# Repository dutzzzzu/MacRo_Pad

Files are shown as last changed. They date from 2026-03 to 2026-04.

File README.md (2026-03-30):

## MacRo Pad

A compact macropad with 6 keys, 2 rotary encoders, and a small OLED display.  
It’s designed for quick media control, productivity shortcuts, and future smart home integration.  
Currently built for macOS. Home Assistant integration and Windows support will be added once the hardware is available.

---
## Overview

<table>
  <tr>
    <td align="center">
      <b>Render</b><br>
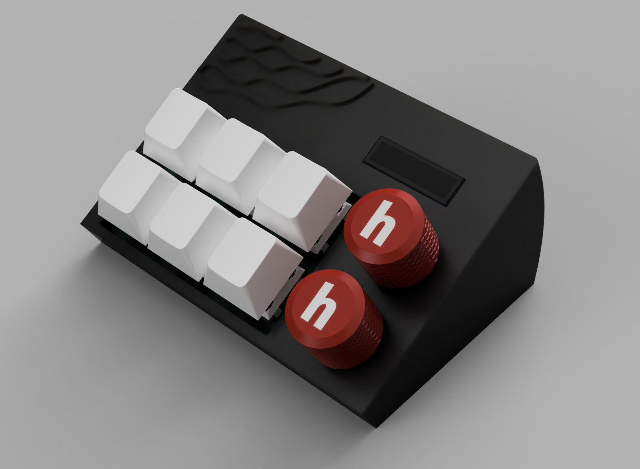
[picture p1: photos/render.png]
      
    </td>
    <td align="center">
      <b>Case</b><br>
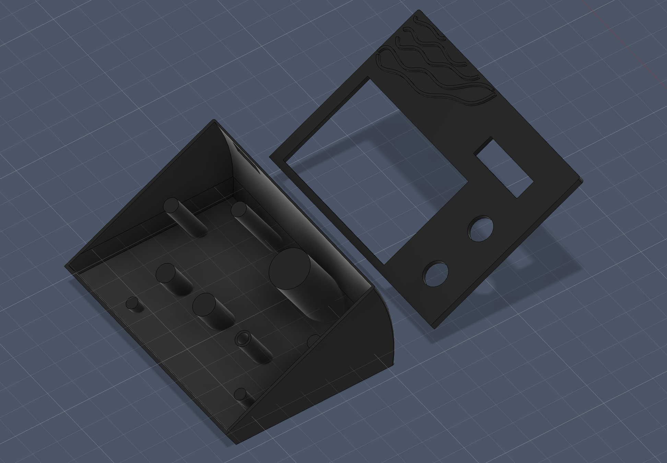
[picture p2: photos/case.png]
      
    </td>
  </tr>
  <tr>
    <td align="center">
      <b>Schematic</b><br>
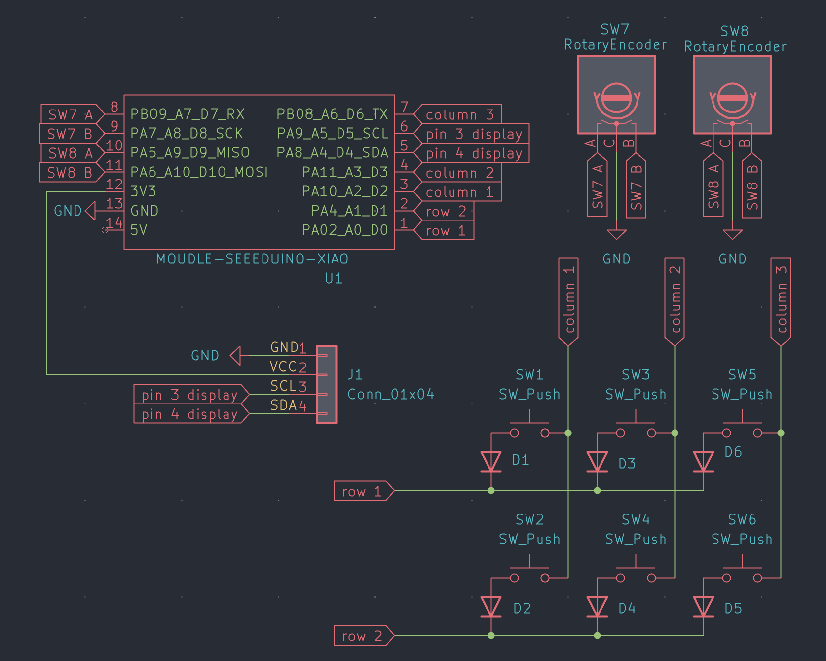
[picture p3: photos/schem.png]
      
    </td>
    <td align="center">
      <b>PCB</b><br>
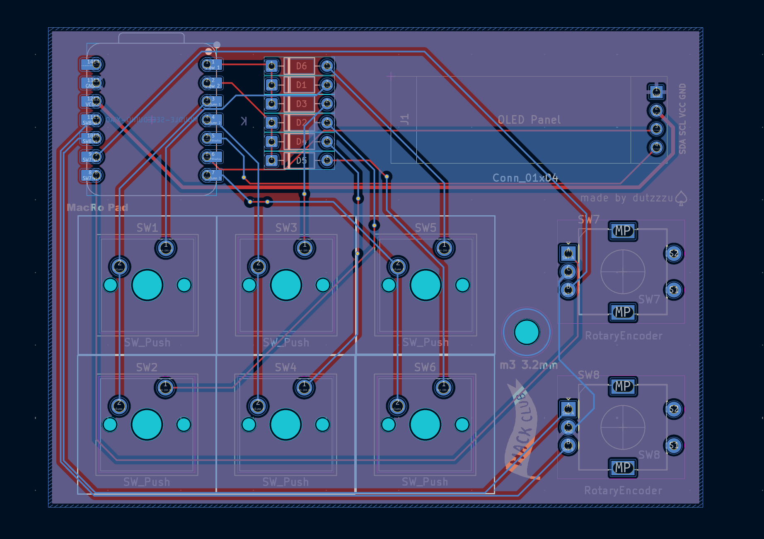
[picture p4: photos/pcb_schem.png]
      
    </td>
  </tr>
</table>

---

## Bill of Materials

| Part | Quantity | Notes |
|---|---|---|
| Seeed XIAO RP2040 | 1 | Main microcontroller |
| MX-style switches | 6 | Mechanical switches |
| DSA keycaps | 6 | Keycaps |
| EC11 rotary encoders | 2 | Rotation only |
| 0.91" OLED display (SSD1306) | 1 | I2C |
| 1N4148 diodes | 6 | Key matrix |
| Custom PCB | 1 | Designed in KiCad |
| 3D printed case | 1 | Custom enclosure |
| 3D printed knobs | 2 | Custom knobs |
| M3 screws | 1 | Assembly |
| M3 heatset inserts | 1 | Mounting |

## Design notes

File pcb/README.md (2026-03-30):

PCB design files for the macropad.
The assembly is made in fusion
## PCB Design

| Layout | PCB (no buttons) |
|---|---|
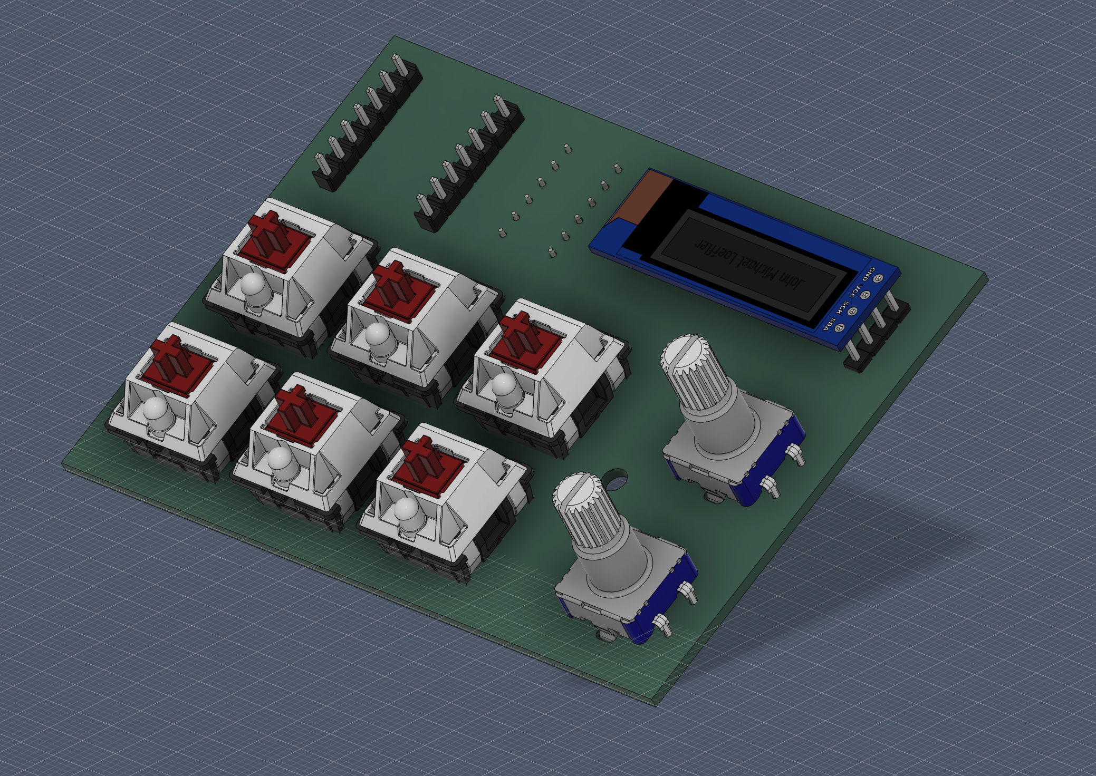
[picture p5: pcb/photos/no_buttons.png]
|  |  |

| Schematic | All Components |
|---|---|
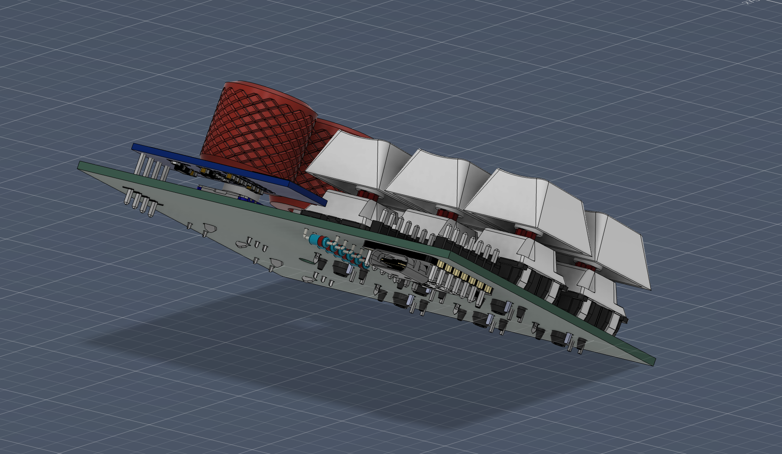
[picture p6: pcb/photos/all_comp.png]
| |  |

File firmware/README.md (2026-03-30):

## Firmware

<table>
<tr>
<td valign="top" width="50%">

### OLED / Encoders
- Encoder 1: volume  
- Encoder 2: brightness / focus volume  
- Key 3: encoder 2 mode  
- Key 6: switch layout  
- OLED shows layout / time / slider  

</td>
<td valign="top" width="50%">

### Productivity

| Key 1 | Key 2 | Key 3 |
|---|---|---|
| Copy | Paste | Encoder mode |

| Key 4 | Key 5 | Key 6 |
|---|---|---|
| Lock screen | Quit app | Switch layout |

</td>
</tr>

<tr>
<td valign="top" width="50%">

### Media

| Key 1 | Key 2 | Key 3 |
|---|---|---|
| Previous track | Next track | Encoder mode |

| Key 4 | Key 5 | Key 6 |
|---|---|---|
| Play / Pause | Open app | Switch layout |

</td>
<td valign="top" width="50%">

### Home Assistant

| Key 1 | Key 2 | Key 3 |
|---|---|---|
| action | action | Encoder mode |

| Key 4 | Key 5 | Key 6 |
|---|---|---|
| action | action | Switch layout |

</td>
</tr>
</table>

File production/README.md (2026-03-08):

# Production

Manufacturing files for the macropad.

| Gerber | Knob |
|---|---|
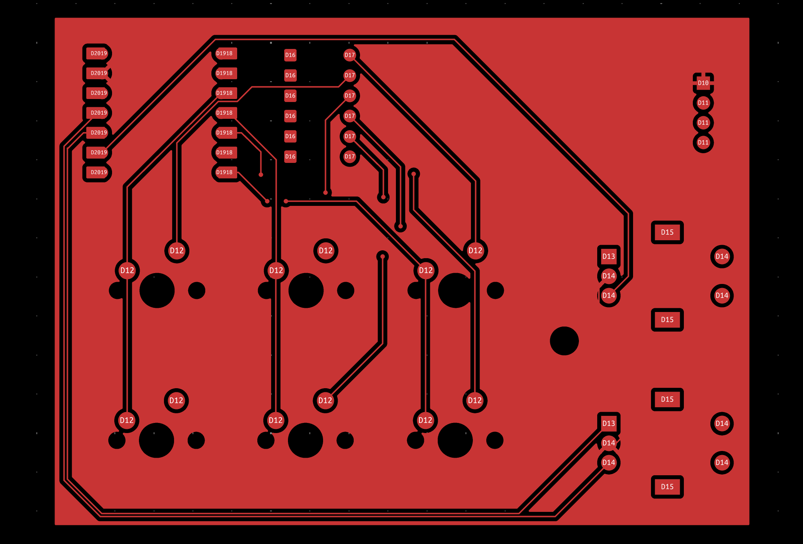
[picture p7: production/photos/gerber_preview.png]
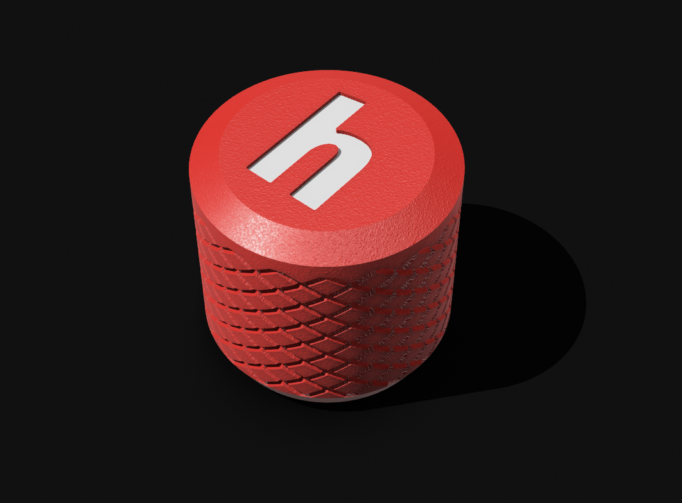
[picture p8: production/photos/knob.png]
|  |  |

| Faceplate | Housing |
|---|---|
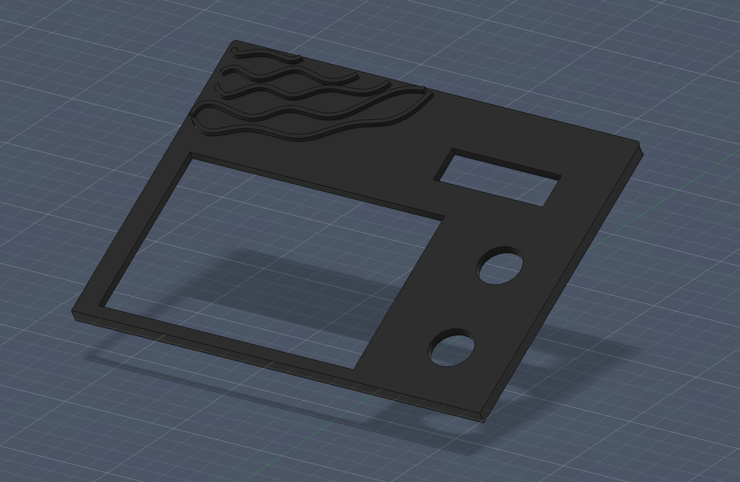
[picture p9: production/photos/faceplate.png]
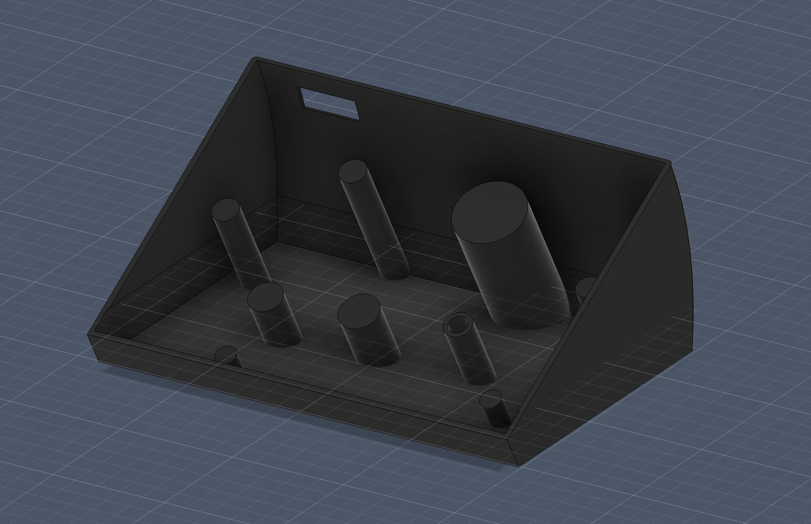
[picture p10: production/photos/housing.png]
|  |  |

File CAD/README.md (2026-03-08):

# CAD

3D models for the MacRo_Pad case.

| Assembly | Case |
|---|---|
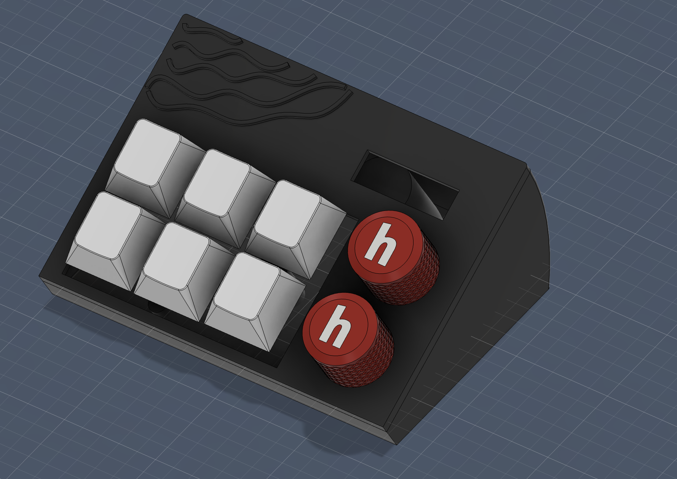
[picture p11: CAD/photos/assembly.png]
|  |  |

| Faceplate | Housing |
|---|---|
|  |  |

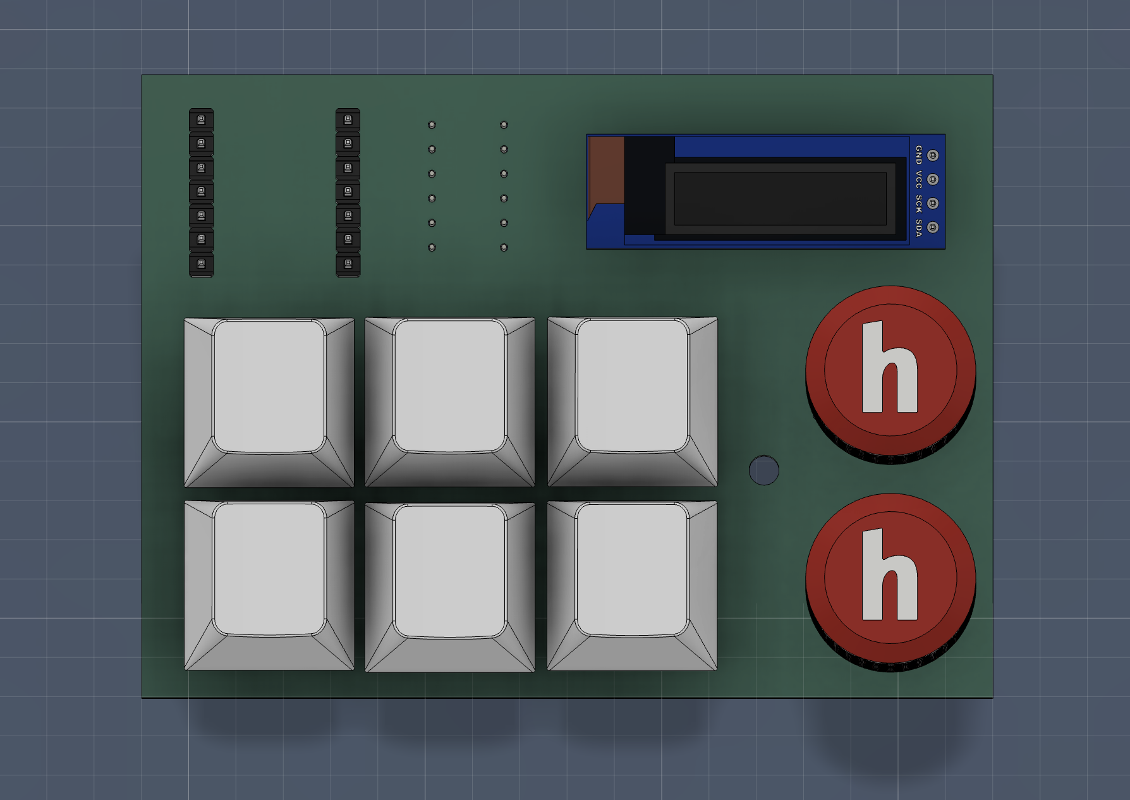
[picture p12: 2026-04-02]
pcb/photos/face.png

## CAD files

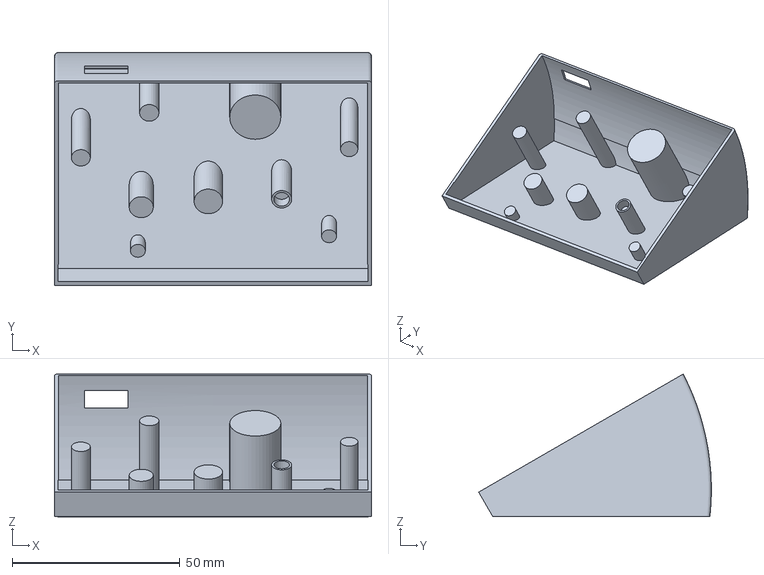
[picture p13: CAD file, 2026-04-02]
CAD/3mf files/housing (1).3mf
94.5 x 69.4 x 42.6 mm

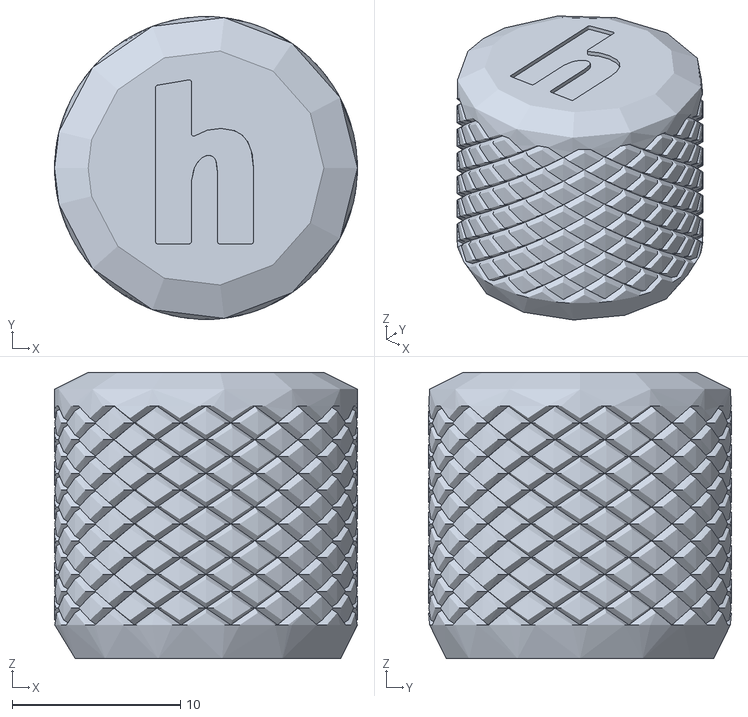
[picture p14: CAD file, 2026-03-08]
production/knurled_knob.step.stl
18.0 x 18.0 x 17.0

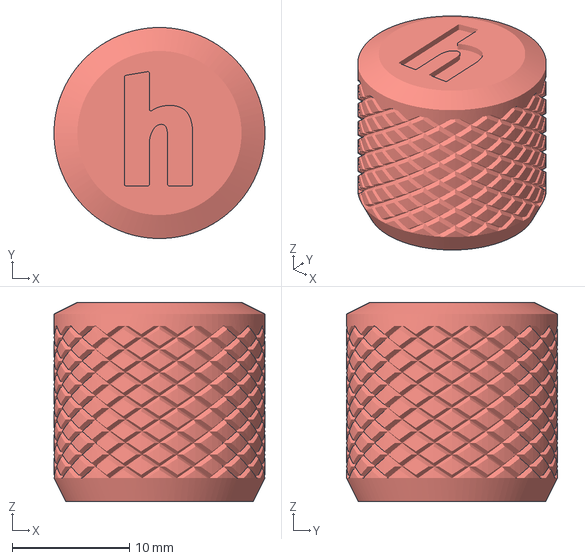
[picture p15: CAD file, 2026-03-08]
CAD/3mf files/knob.3mf
18.0 x 18.0 x 17.0 mm

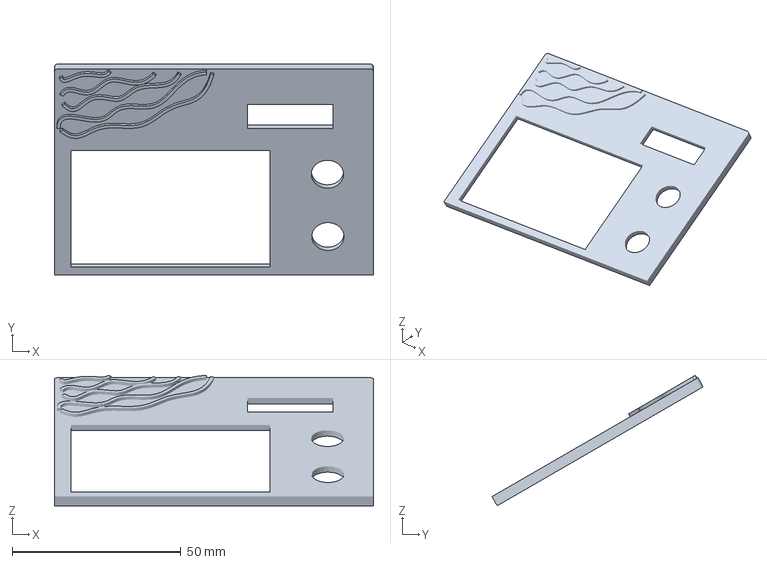
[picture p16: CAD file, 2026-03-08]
CAD/3mf files/faceplate.3mf
94.5 x 62.5 x 38.7 mm

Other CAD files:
CAD/step files/housing .step
production/step files/housing .step
production/step files/knurled_knob.step
production/step files/faceplate.step
CAD/STL files/housing.stl
CAD/step files/housing.step
production/faceplate.stl

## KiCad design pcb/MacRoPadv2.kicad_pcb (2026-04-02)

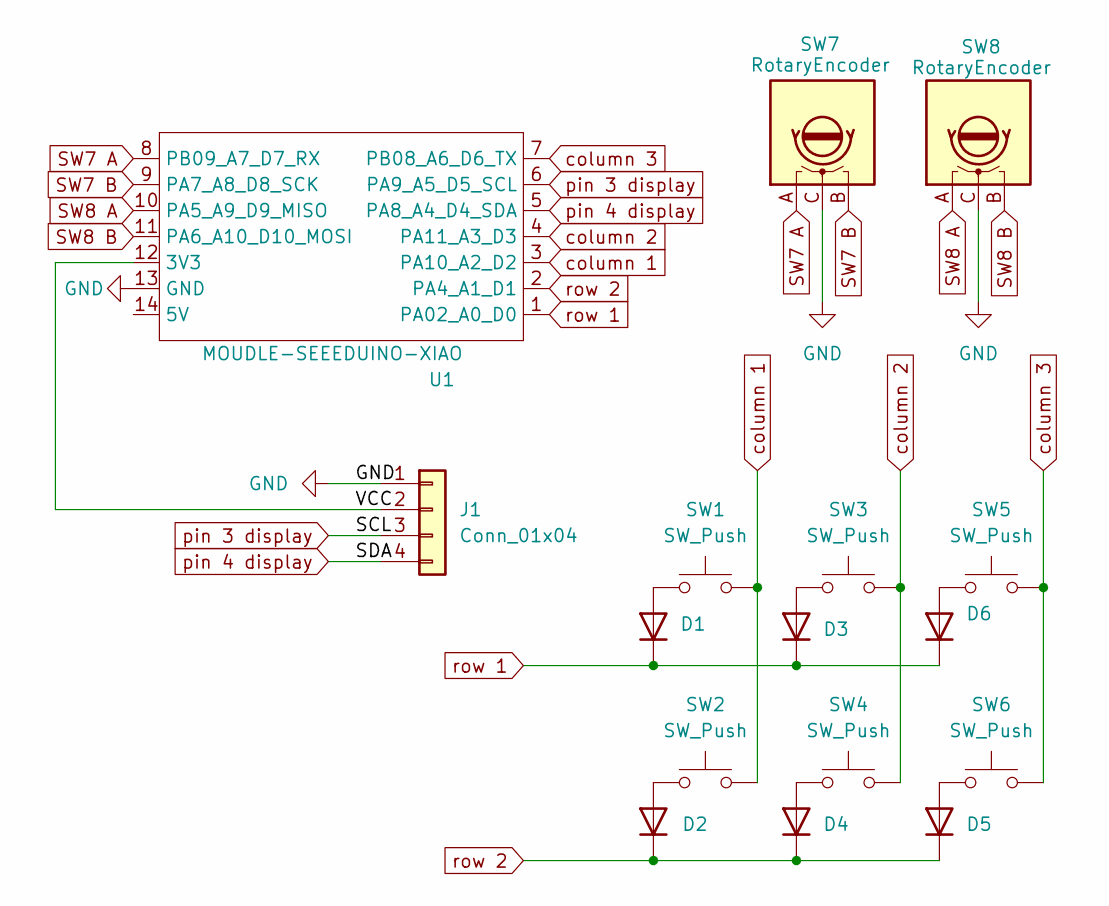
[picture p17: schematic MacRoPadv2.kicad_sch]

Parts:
D1, D2, D3, D4, D5, D6: 1N4148; D_DO-35_SOD27_P7.62mm_Horizontal
J1: Conn_01x04; SSD1306-0.91-OLED-4pin-128x32
SW1, SW2, SW3, SW4, SW5, SW6: SW_Push; SW_Cherry_MX_1.00u_PCB
SW7, SW8: RotaryEncoder; RotaryEncoder_Alps_EC11E-Switch_Vertical_H20mm
U1: MOUDLE-SEEEDUINO-XIAO; XIAO-RP2040-DIP

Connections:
/VCC: J1.2, U1.12 (3V3)
GND: J1.1, SW7.C, SW8.C, U1.13 (GND)
unnamed: D1.2 (A), SW1.1
unnamed: D2.2 (A), SW2.1
unnamed: D3.2 (A), SW3.1
unnamed: D4.2 (A), SW4.1
unnamed: D5.2 (A), SW6.1
unnamed: D6.2 (A), SW5.1
SW7 A: SW7.A, U1.8 (PB09_A7_D7_RX)
SW7 B: SW7.B, U1.9 (PA7_A8_D8_SCK)
SW8 A: SW8.A, U1.10 (PA5_A9_D9_MISO)
SW8 B: SW8.B, U1.11 (PA6_A10_D10_MOSI)
column 1: SW1.2, SW2.2, U1.3 (PA10_A2_D2)
column 2: SW3.2, SW4.2, U1.4 (PA11_A3_D3)
column 3: SW5.2, SW6.2, U1.7 (PB08_A6_D6_TX)
pin 3 display: J1.3, U1.6 (PA9_A5_D5_SCL)
pin 4 display: J1.4, U1.5 (PA8_A4_D4_SDA)
row 1: D1.1 (K), D3.1 (K), D6.1 (K), U1.1 (PA02_A0_D0)
row 2: D2.1 (K), D4.1 (K), D5.1 (K), U1.2 (PA4_A1_D1)

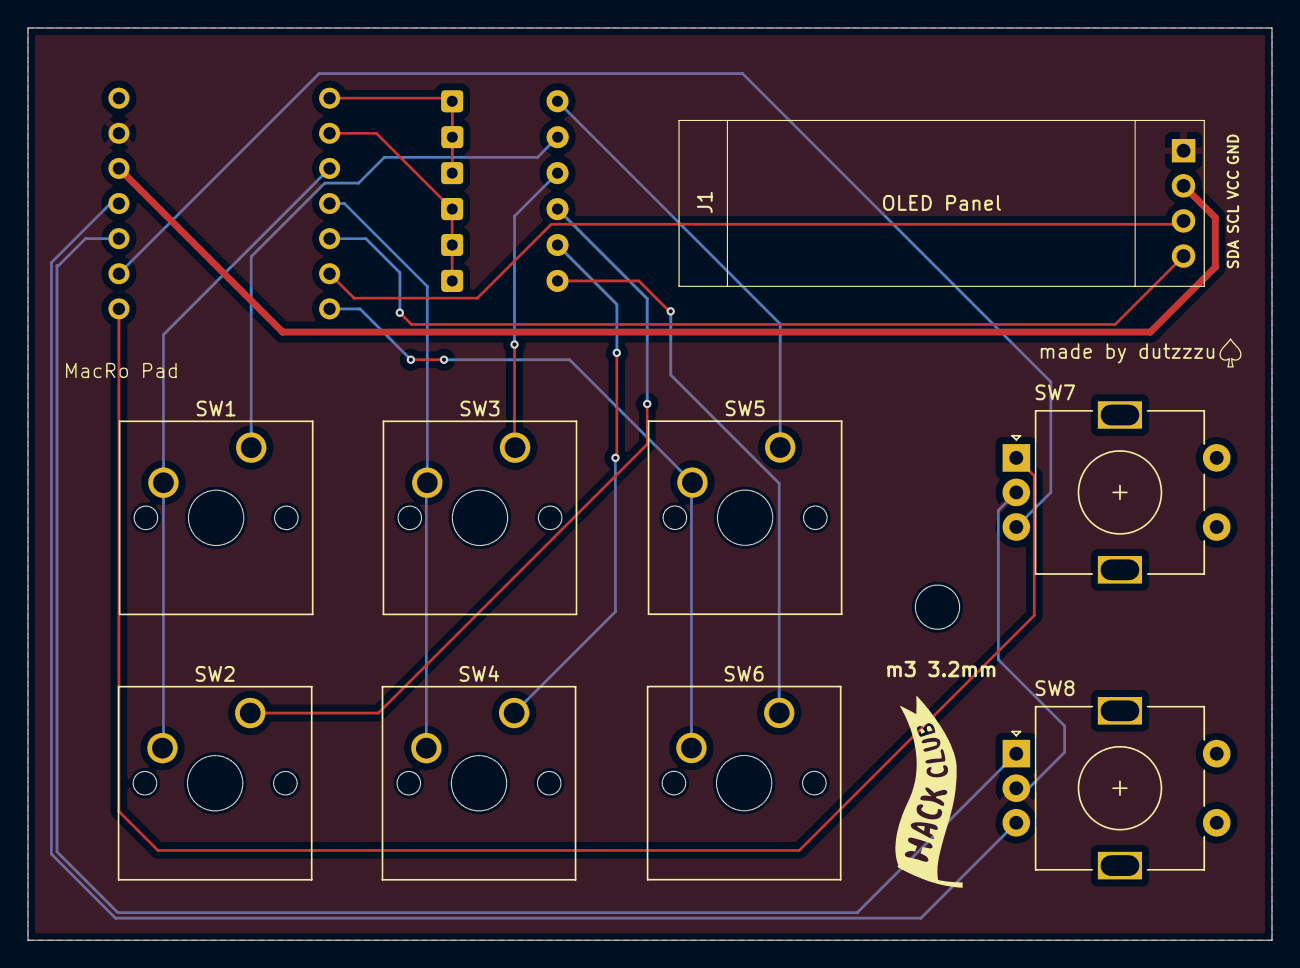
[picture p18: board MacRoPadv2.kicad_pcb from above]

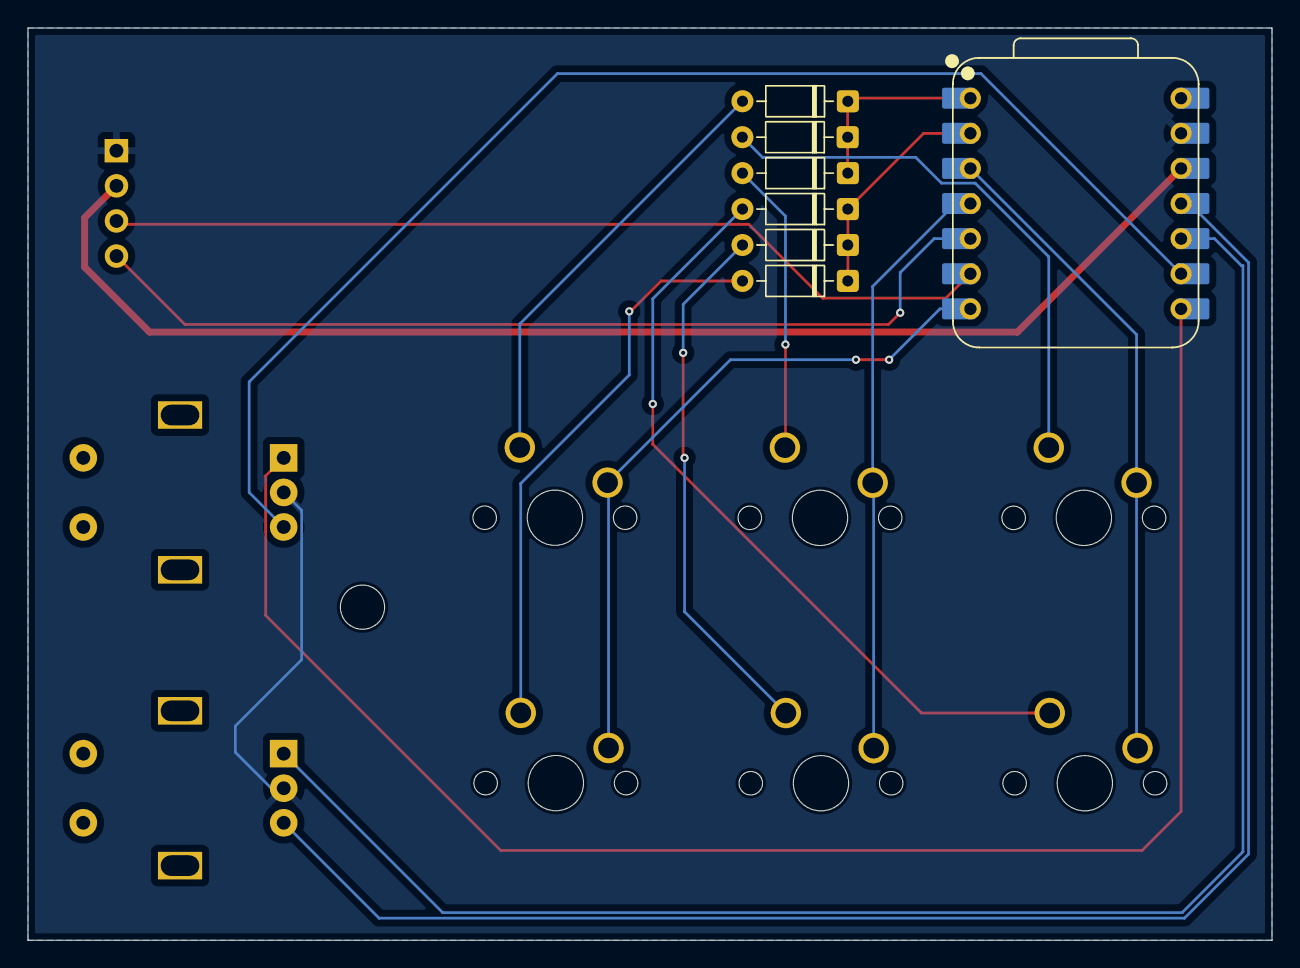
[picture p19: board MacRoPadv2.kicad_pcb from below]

Board: 2 copper layers, 90.0 x 66.0 mm, 16 parts (7 on the bottom side), 19 nets.

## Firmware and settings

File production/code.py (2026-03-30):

import time

try:
    import board
    import busio
    import displayio
    import keypad
    import rotaryio
    import terminalio
    import usb_hid
    from adafruit_display_text import label
    from adafruit_displayio_ssd1306 import SSD1306
    from adafruit_hid.consumer_control import ConsumerControl
    from adafruit_hid.consumer_control_code import ConsumerControlCode
    from adafruit_hid.keyboard import Keyboard
    from adafruit_hid.keycode import Keycode
    from adafruit_hid.keyboard_layout_us import KeyboardLayoutUS

    CIRCUITPYTHON_READY = True
except ImportError as import_error:
    CIRCUITPYTHON_READY = False
    print("CircuitPython libraries not available:", import_error)


DISPLAY_WIDTH = 128
DISPLAY_HEIGHT = 32
DISPLAY_I2C_ADDRESS = 0x3C
COLUMNS_TO_ANODES = True

IDLE_TIMEOUT_SECONDS = 15
METRIC_OVERLAY_SECONDS = 2
PERCENT_STEP = 5

LAYER_PRODUCTIVITY = 0
LAYER_MEDIA = 1
LAYER_HOME = 2
LAYER_NAMES = ("PRODUCTIVITY", "MEDIA", "HOME")

ENCODER2_MODE_BRIGHTNESS = 0
ENCODER2_MODE_FOCUS_VOLUME = 1
ENCODER2_MODE_NAMES = ("BRIGHTNESS", "FOCUS_VOLUME")
ENCODER2_MODE_SHORT_NAMES = ("BRIGHT", "FOCUS")

SPOTLIGHT_OPEN_DELAY = 0.25
SPOTLIGHT_TYPE_DELAY = 0.10

SLIDER_X = 10
SLIDER_Y = 26
SLIDER_WIDTH = 108
SLIDER_HEIGHT = 6


current_layer = LAYER_PRODUCTIVITY
encoder2_mode = ENCODER2_MODE_BRIGHTNESS

master_volume_percent = 50
brightness_percent = 50
focus_volume_percent = 50

last_interaction_time = time.monotonic()
metric_overlay_until = 0.0
metric_title = ""
metric_percent = 0
last_display_signature = None
last_display_state = None

keyboard = None
keyboard_layout = None
consumer_control = None
matrix = None
encoder1 = None
encoder2 = None
encoder1_last_position = 0
encoder2_last_position = 0

display = None
title_label = None
detail_label = None
slider_bitmap = None


def debug(message):
    print("[DEBUG]", message)


def get_pin(name):
    try:
        return getattr(board, name)
    except AttributeError:
        debug("Pin {} is not available on this board.".format(name))
        return None


MATRIX_ROWS = (get_pin("D1"), get_pin("D2")) if CIRCUITPYTHON_READY else ()
MATRIX_COLUMNS = (get_pin("D3"), get_pin("D4"), get_pin("D5")) if CIRCUITPYTHON_READY else ()
ENCODER1_A_PIN = get_pin("D8") if CIRCUITPYTHON_READY else None
ENCODER1_B_PIN = get_pin("D9") if CIRCUITPYTHON_READY else None
ENCODER2_A_PIN = get_pin("D10") if CIRCUITPYTHON_READY else None
ENCODER2_B_PIN = get_pin("D11") if CIRCUITPYTHON_READY else None


def clamp(value, low, high):
    return max(low, min(high, value))


def record_interaction(_source=None):
    global last_interaction_time

    last_interaction_time = time.monotonic()


def set_metric_overlay(title, percent):
    global metric_title
    global metric_percent
    global metric_overlay_until

    metric_title = title
    metric_percent = clamp(percent, 0, 100)
    metric_overlay_until = time.monotonic() + METRIC_OVERLAY_SECONDS


def tap_keys(*keycodes):
    if keyboard is None:
        debug("Keyboard HID is not ready.")
        return

    keyboard.send(*keycodes)


def send_text(text):
    if keyboard_layout is None:
        debug("Keyboard layout is not ready.")
        return

    keyboard_layout.write(text)


def send_consumer(code):
    if consumer_control is None:
        debug("ConsumerControl HID is not ready.")
        return

    consumer_control.send(code)


def action_copy():
    debug("Action: Copy")
    tap_keys(Keycode.COMMAND, Keycode.C)


def action_paste():
    debug("Action: Paste")
    tap_keys(Keycode.COMMAND, Keycode.V)


def action_lock_screen():
    debug("Action: Lock Screen")
    tap_keys(Keycode.CONTROL, Keycode.COMMAND, Keycode.Q)


def action_quit_application():
    debug("Action: Quit Application")
    tap_keys(Keycode.COMMAND, Keycode.Q)


def action_backtrack():
    debug("Action: Backtrack")
    send_consumer(ConsumerControlCode.SCAN_PREVIOUS_TRACK)


def action_skip():
    debug("Action: Skip")
    send_consumer(ConsumerControlCode.SCAN_NEXT_TRACK)


def action_play_pause():
    debug("Action: Play/Pause")
    send_consumer(ConsumerControlCode.PLAY_PAUSE)


def action_open_spotify():
    debug("Action: Open Spotify")
    if keyboard is None or keyboard_layout is None:
        debug("Spotify launch skipped because keyboard HID is not ready.")
        return

    tap_keys(Keycode.COMMAND, Keycode.SPACE)
    time.sleep(SPOTLIGHT_OPEN_DELAY)
    send_text("Spotify")
    time.sleep(SPOTLIGHT_TYPE_DELAY)
    tap_keys(Keycode.ENTER)


def action_toggle_encoder2_mode():
    toggle_encoder2_mode()


def action_switch_layout():
    cycle_layer()


def make_home_action(index):
    def _action():
        debug("HOME placeholder action for key {}".format(index))

    return _action


# Key order is row-major:
# key 1, key 2, key 3
# key 4, key 5, key 6
#
# Fixed system keys:
# key 3 -> Encoder 2 Mode
# key 6 -> Switch Layout
LAYER_ACTIONS = {
    LAYER_PRODUCTIVITY: (
        action_copy,
        action_paste,
        action_toggle_encoder2_mode,
        action_lock_screen,
        action_quit_application,
        action_switch_layout,
    ),
    LAYER_MEDIA: (
        action_backtrack,
        action_skip,
        action_toggle_encoder2_mode,
        action_play_pause,
        action_open_spotify,
        action_switch_layout,
    ),
    LAYER_HOME: (
        make_home_action(1),
        make_home_action(2),
        action_toggle_encoder2_mode,
        make_home_action(4),
        make_home_action(5),
        action_switch_layout,
    ),
}


def current_time_text():
    try:
        now = time.localtime()
        if now.tm_year < 2024:
            return "--:--"
        return "{:02d}:{:02d}".format(now.tm_hour, now.tm_min)
    except Exception as error:
        debug("Time read failed: {}".format(error))
        return "--:--"


def center_text(text_label, text, y):
    text_label.text = text
    text_label.y = y

    if text:
        bounds = text_label.bounding_box
        text_label.x = max(0, (DISPLAY_WIDTH - bounds[2]) // 2)
    else:
        text_label.x = 0


def clear_slider():
    if slider_bitmap is None:
        return

    for x in range(SLIDER_WIDTH):
        for y in range(SLIDER_HEIGHT):
            slider_bitmap[x, y] = 0


def draw_slider(percent):
    if slider_bitmap is None:
        return

    clear_slider()

    for x in range(SLIDER_WIDTH):
        slider_bitmap[x, 0] = 1
        slider_bitmap[x, SLIDER_HEIGHT - 1] = 1

    for y in range(SLIDER_HEIGHT):
        slider_bitmap[0, y] = 1
        slider_bitmap[SLIDER_WIDTH - 1, y] = 1

    fill_width = int((SLIDER_WIDTH - 2) * clamp(percent, 0, 100) / 100)
    for x in range(1, fill_width + 1):
        for y in range(1, SLIDER_HEIGHT - 1):
            slider_bitmap[x, y] = 1
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
